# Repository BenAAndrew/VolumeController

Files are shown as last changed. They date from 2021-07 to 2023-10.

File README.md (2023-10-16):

# Volume Controller

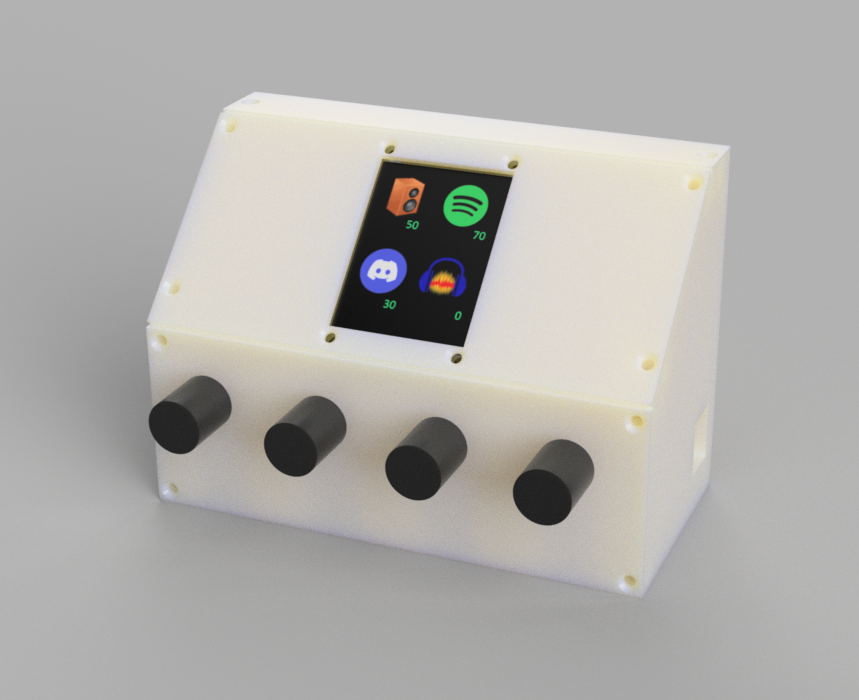
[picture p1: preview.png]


A physical multi-app volume controller. Control master volume and up to 3 other apps.

# Setup

## Parts
- Arduino Mega 2560
- ST7735 1.8" Color TFT Display
- 4x Rotary Encoders & Knobs
- Breadboard
- Wires

## [Wiring](firmware/WIRING.md)

## Installation

1. Upload the [Arduino sketch in the firmware folder](firmware/firmware.ino) to your Arduino
2. Run the desktop app. To do this you can either:
    - Download the executable in Releases and run
    - Install Python, dependencies and run `python main.py`

If this is done correctly the volume controller should now be working.

## [Assembly](assembly/ASSEMBLY.md)

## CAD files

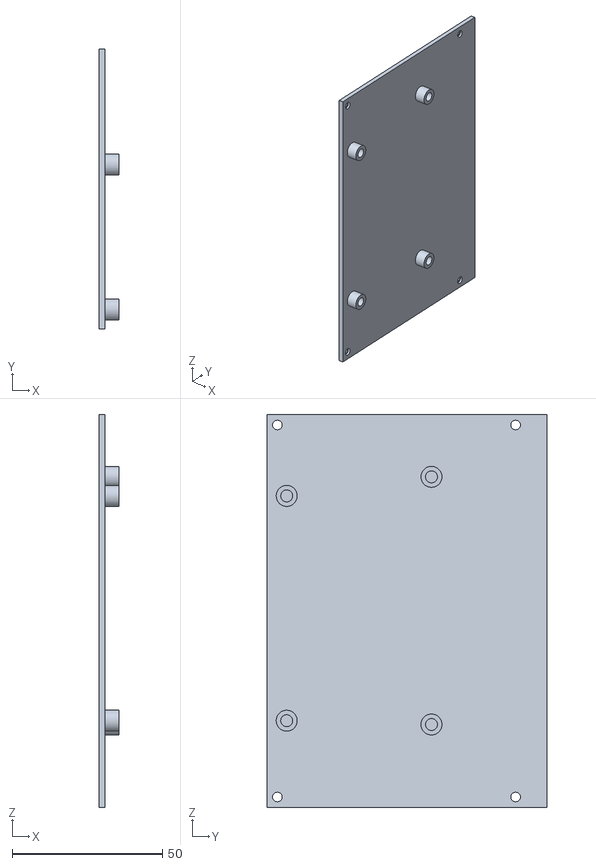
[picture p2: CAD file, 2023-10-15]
assembly/3d_models/Back.stl
6.80 x 93.4 x 131.0

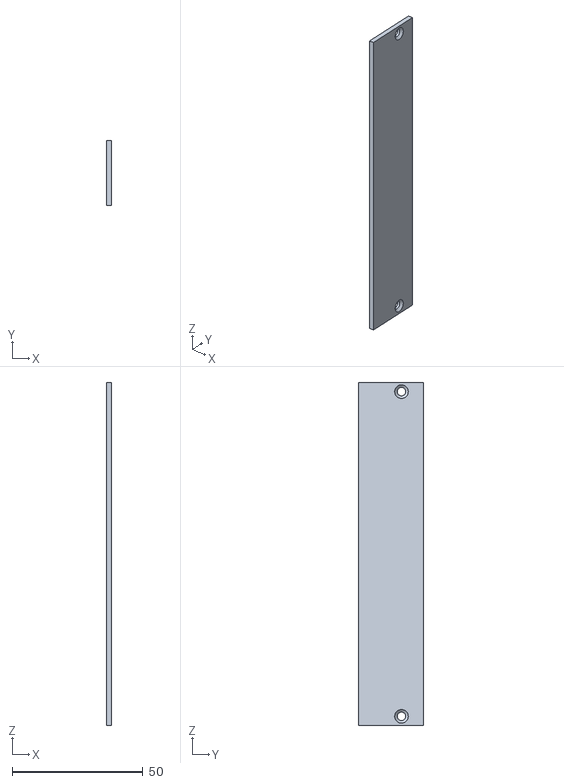
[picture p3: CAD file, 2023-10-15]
assembly/3d_models/Top.stl
2.00 x 25.0 x 131.0

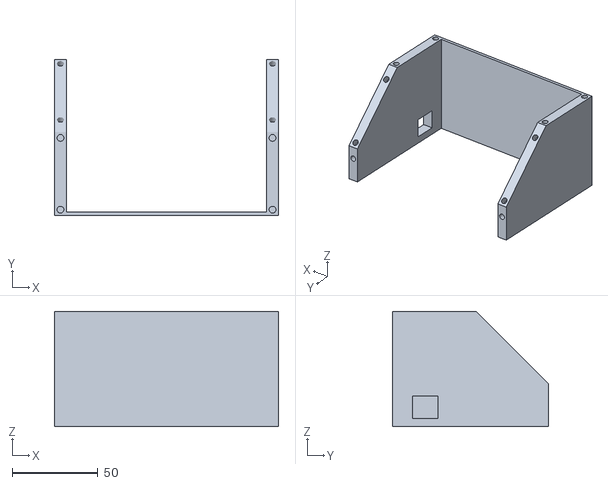
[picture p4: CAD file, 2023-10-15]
assembly/3d_models/Body.stl
131.0 x 91.4 x 67.4

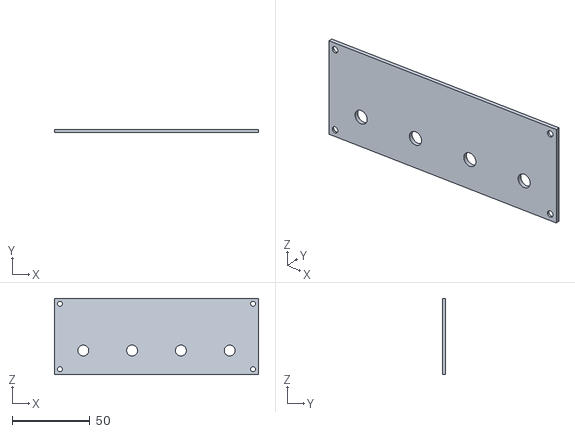
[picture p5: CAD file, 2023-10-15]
assembly/3d_models/Front.stl
131.0 x 2.00 x 49.0

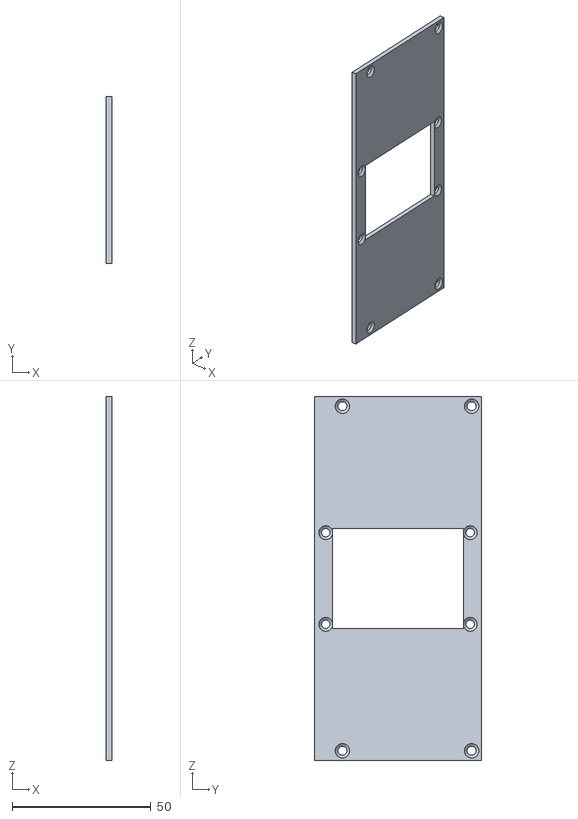
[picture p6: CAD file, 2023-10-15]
assembly/3d_models/Screen.stl
2.00 x 60.0 x 131.0

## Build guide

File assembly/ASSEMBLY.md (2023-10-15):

# Assembly

Before starting assembly, make sure you have the [electronics working and wires attached](../firmware/WIRING.md).

## Option A: 3D print
1. 3D print one of each STL file found in this folder
2. Insert [M3 heat inserts](https://uk.rs-online.com/web/p/threaded-inserts/0278534) into each hole on the body and the back piece
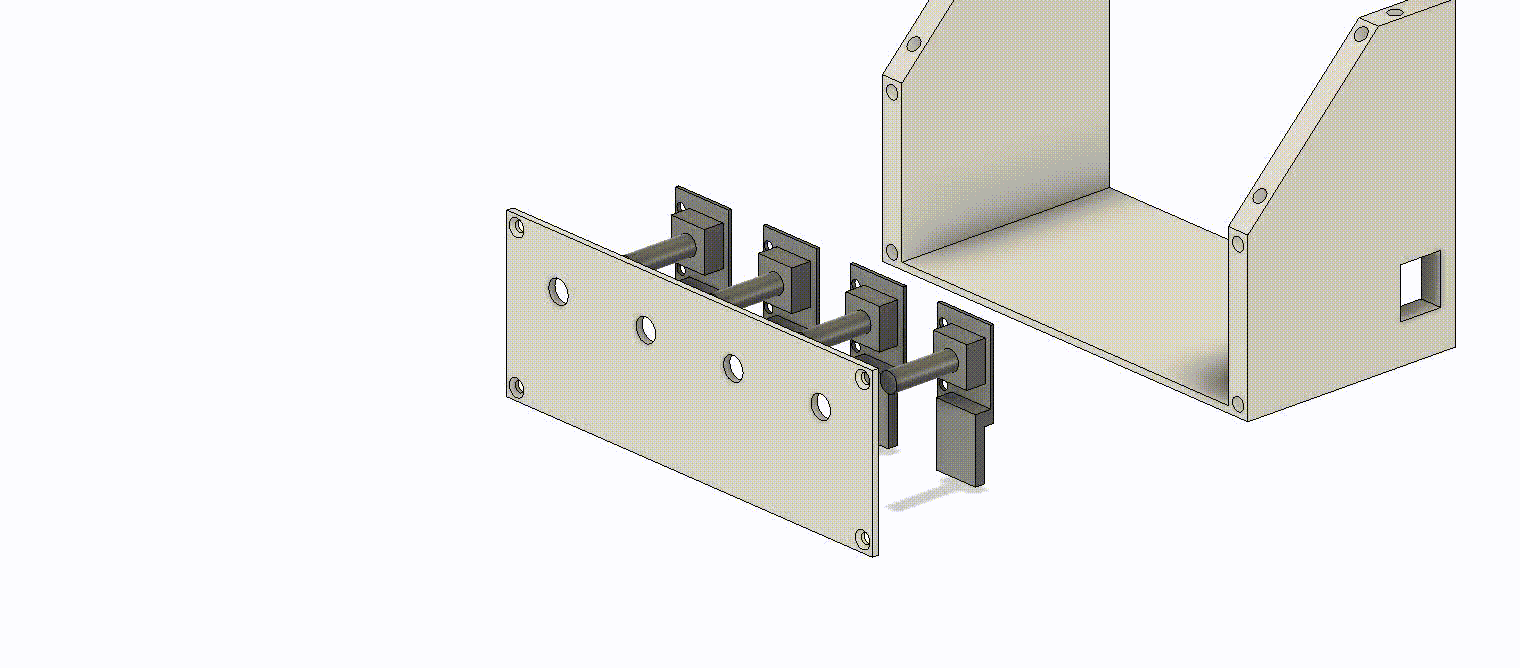
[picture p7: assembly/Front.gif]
3. Insert the encoders into the front piece, secure each with nuts, attach the knobs and then attach to the body 
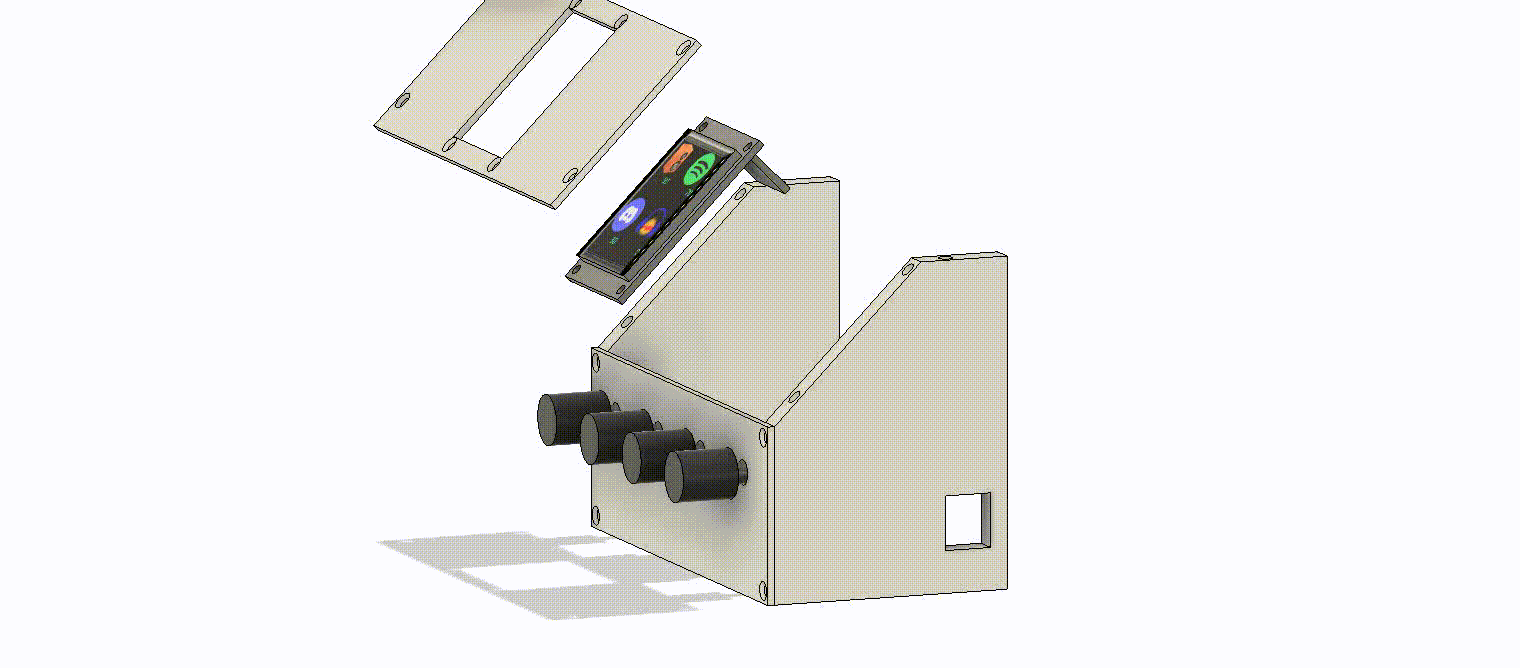
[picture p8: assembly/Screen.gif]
4. Insert the screen into the screen piece, then attach to the body 
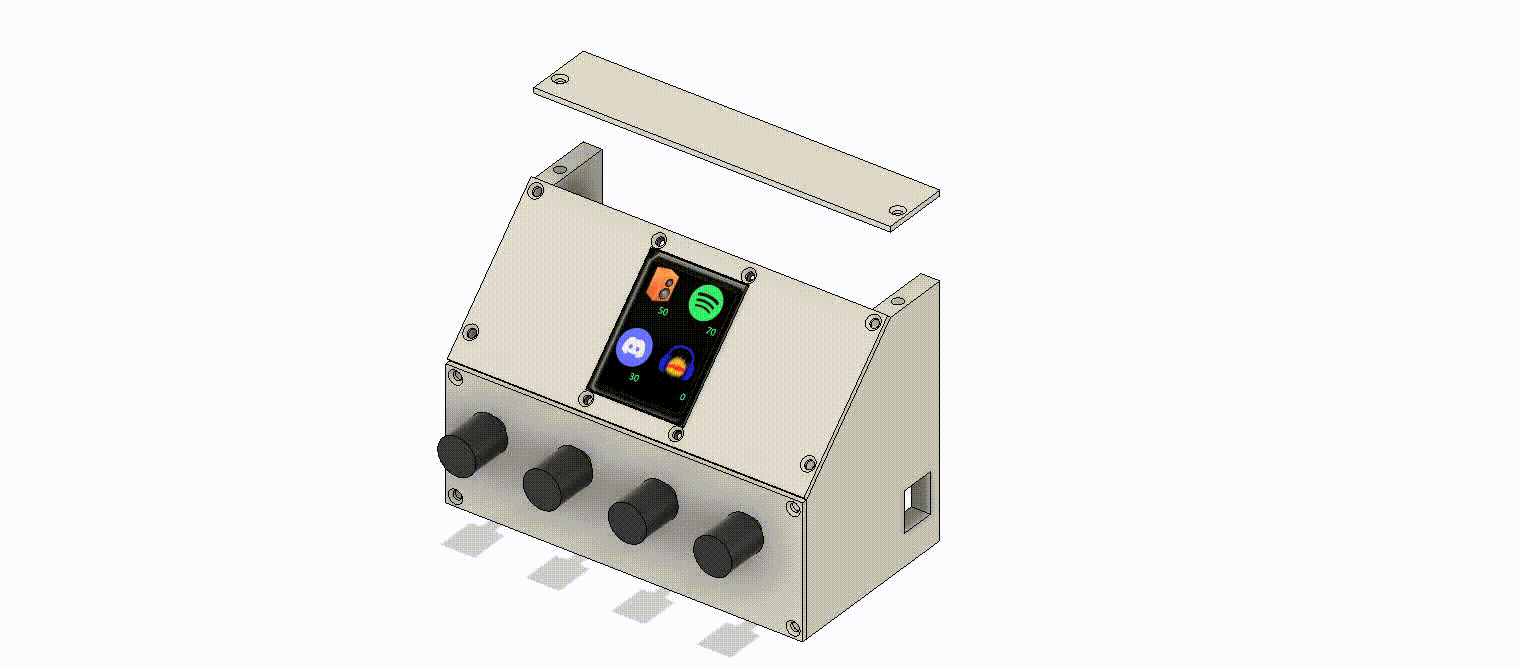
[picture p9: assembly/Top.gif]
5. Attach the top piece to the body 
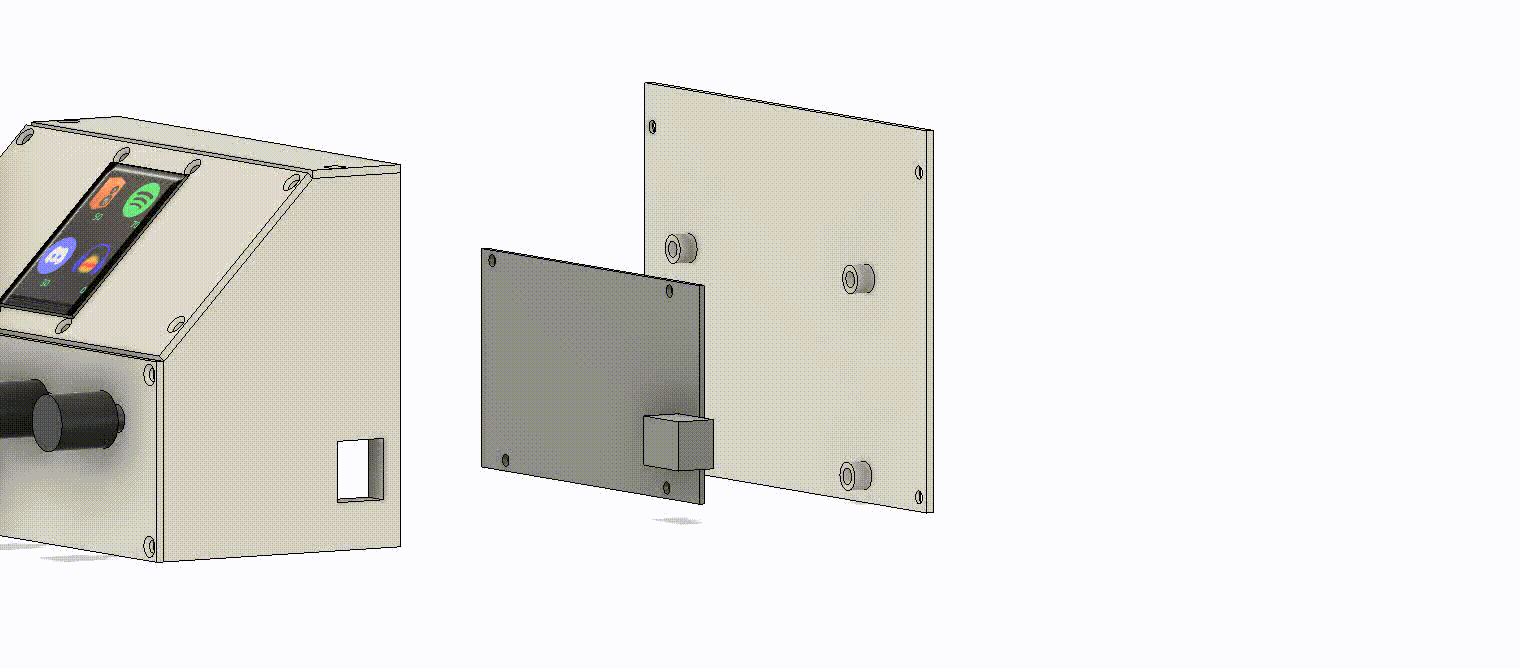
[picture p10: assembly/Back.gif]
6. Attach the arduino to the back piece, then attach to the body 

## Option B: 2D cut
Coming soon

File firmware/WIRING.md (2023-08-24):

# Wiring

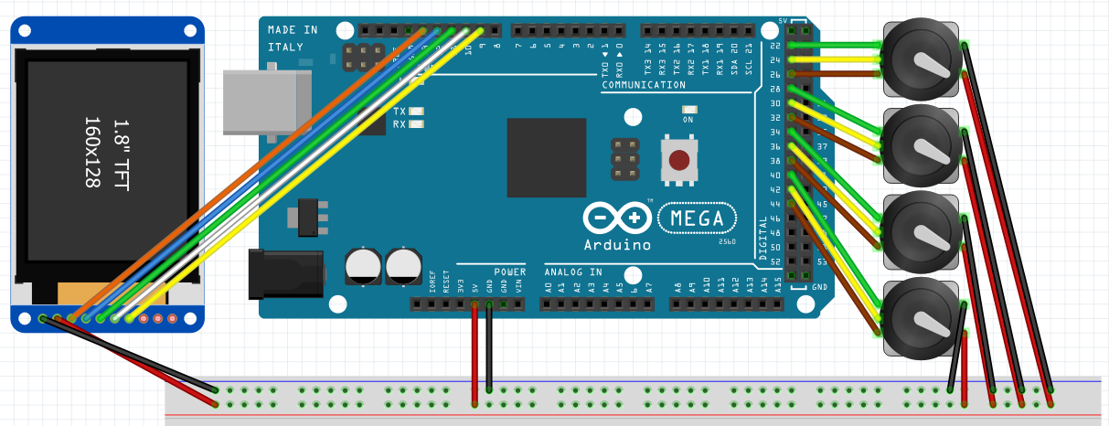
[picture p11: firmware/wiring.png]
wiring


## Display
- VCC = 5V
- GND = GND
- CLK/SCK = 13
- MOSI/SDA = 12
- CS = 11
- DC = 10
- RST = 9

8th Pin unconnected.

## Rotary encoders
- VCC/+ = 5V
- GND = GND

Master volume:
- SW = 22
- DT = 24
- CLK = 26

App 1:
- SW = 28
- DT = 30
- CLK = 32

App 2:
- SW = 34
- DT = 36
- CLK = 38

App 3:
- SW = 40
- DT = 42
- CLK = 44

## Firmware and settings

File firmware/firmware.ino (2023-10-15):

#include <Adafruit_GFX.h>    // Core graphics library
#include <Adafruit_ST7735.h> // Hardware-specific library
#include "Rotary_Encoder.h" // Hardware-specific library
#include <SPI.h>

// TFT Screen
#define sclk 13
#define mosi 12
#define cs   11
#define dc   10
#define rst  9

#define icon_size 60
#define icon_area icon_size*icon_size
#define margin_x 2
#define margin_y 10

Adafruit_ST7735 tft = Adafruit_ST7735(cs, dc, mosi, sclk, rst);
uint8_t r;
uint8_t g;
uint8_t b;

// Encoders
#define numEncoders 4
#define stepSize 2
#define pushDuration 10000

#define encoder1A 26
#define encoder1B 24
#define encoder1Btn 22

#define encoder2A 32
#define encoder2B 30
#define encoder2Btn 28

#define encoder3A 38
#define encoder3B 36
#define encoder3Btn 34

#define encoder4A 44
#define encoder4B 42
#define encoder4Btn 40

Rotary_Encoder encoders[] = {
  Rotary_Encoder(encoder1A, encoder1B, encoder1Btn, digitalRead(encoder1A)),
  Rotary_Encoder(encoder2A, encoder2B, encoder2Btn, digitalRead(encoder2A)),
  Rotary_Encoder(encoder3A, encoder3B, encoder3Btn, digitalRead(encoder3A)),
  Rotary_Encoder(encoder4A, encoder4B, encoder4Btn, digitalRead(encoder4A)),
};

// Variables
uint8_t command;
uint8_t output;
bool isConnected = false;

void setup() {
  // Screen setup
  tft.initR(INITR_BLACKTAB);
  tft.fillScreen(ST7735_BLACK);
  tft.setTextColor(ST7735_GREEN, ST7735_BLACK);
  tft.setTextSize(1);
  displayText(0, 150, "WAITING FOR APP...");

  // Encoder setup
  pinMode(encoder1A, INPUT);
  pinMode(encoder1B, INPUT);
  pinMode(encoder1Btn, INPUT_PULLUP);

  pinMode(encoder2A, INPUT);
  pinMode(encoder2B, INPUT);
  pinMode(encoder2Btn, INPUT_PULLUP);
  
  pinMode(encoder3A, INPUT);
  pinMode(encoder3B, INPUT);
  pinMode(encoder3Btn, INPUT_PULLUP);

  pinMode(encoder4A, INPUT);
  pinMode(encoder4B, INPUT);
  pinMode(encoder4Btn, INPUT_PULLUP);
  
  Serial.begin(14400);
}

void loop() {
  if (Serial.available() > 0) {
    command = getNextInput();
    if(command == 'i'){
      drawIcon();
    } else if(command == 'v'){
      displayVolume();
    } else if(command == 'm'){
      muteApp();
    } else if(command == 'd'){
      deleteApp();
    }
    if(!isConnected){
      isConnected = true;
      tft.fillRect(0, 150, 128, 160, ST7735_BLACK); 
    }
    Serial.write('d');
  }
  checkEncoders();
}

void checkEncoders(){
  for(uint8_t i = 0; i < numEncoders; i++){
    output = encoders[i].update(digitalRead(encoders[i].pinA), digitalRead(encoders[i].pinB), digitalRead(encoders[i].pinBtn));
    if(output != 0)
      Serial.write(output + (i * 10));
  }
}

uint8_t getXPosition(uint8_t index){
  uint8_t x = margin_x;
  if(index % 2 == 1){
    x += margin_x + icon_size;
  }
  return x;
}

uint8_t getYPosition(uint8_t index){
  uint8_t y = margin_y;
  if(index > 1){
    y += margin_y*2 + icon_size;
  }
  return y;
}

void displayText(uint8_t x, uint8_t y, String text){
  tft.setCursor(x,y);
  tft.print(text);
}

void displayVolume(){
  uint8_t pos = getNextInput();
  uint8_t volume = getNextInput();
  String text = String(volume) + ' ';
  if(volume < 9){
    text += ' ';
  }
  if(volume < 99){
    text += ' ';
  }
  uint8_t x = getXPosition(pos);
  uint8_t y = getYPosition(pos);
  displayText(x, y, text);
}

void drawIcon(){
  uint8_t pos = getNextInput();
  uint8_t x = getXPosition(pos);
  uint8_t y = getYPosition(pos);
  uint8_t starting_x = x;

  // Colours
  uint8_t num_colours = getNextInput();
  int colours[num_colours];
  for(uint8_t i = 0; i < num_colours; i++){
    r = getNextInput();
    g = getNextInput();
    b = getNextInput();
    colours[i] = tft.color565(r,g,b);
  }

  // Drawing
  uint8_t index;
  for(int pixel_counter = 0; pixel_counter < icon_area; pixel_counter++){
    index = getNextInput();
    tft.drawPixel(x, y, colours[index]);
    if(x == icon_size-1+starting_x){
      x = starting_x;
      y++;
    } else {
      x++;
    }
  }
}

void muteApp(){
  uint8_t pos = getNextInput();
  uint8_t x = getXPosition(pos);
  uint8_t y = getYPosition(pos);
  displayText(x, y, "MUTE");
}

void deleteApp(){
  uint8_t pos = getNextInput();
  uint8_t x = getXPosition(pos);
  uint8_t y = getYPosition(pos);
  tft.fillRect(x, y, x+icon_size, y+icon_size, ST7735_BLACK);
}

uint8_t getNextInput() {
  while(!Serial.available());
  return Serial.read();
}

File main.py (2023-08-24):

import threading
from comtypes import CoInitialize, CoUninitialize

from volume_controller.app import Application
from volume_controller.manager import Manager

thread = None
stop_thread = False


def close():
    global thread, stop_thread
    stop_thread = True
    thread.join()


def main(app):
    CoInitialize()
    manager = Manager(app)
    try:
        while not stop_thread:
            manager.update()
    except Exception as e:
        CoUninitialize()
        raise e


app = Application(on_close=close)
thread = threading.Thread(target=main, args=(app,))
thread.start()
app.run()

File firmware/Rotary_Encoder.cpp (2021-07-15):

#include "Rotary_Encoder.h"

Rotary_Encoder::Rotary_Encoder(unsigned int _pinA, unsigned int _pinB, unsigned int _pinBtn, unsigned int _a){
  index = 0;
  pinA = _pinA;
  pinB = _pinB;
  pinBtn = _pinBtn;
  pushDuration = 0;
  pushed = false;
  stepThreshold = 2;
  pushThreshold = 10000;
  previousVal = _a;
}

unsigned int Rotary_Encoder::update(unsigned int _a, unsigned int _b, unsigned int _button){
  // Push
  if (_button == 0 && !pushed){
    pushDuration++;
    if(pushDuration == pushThreshold){
      pushed = true;
      return index*10+3;
    }
  } else if(_button == 1){
    pushed = false;
    pushDuration = 0;
  }

  // Rotate
  if (_a != previousVal) {
    previousVal = _a;
    if (_b != _a) {
      totalRotation++;
      if(totalRotation == stepThreshold){
        totalRotation = 0;
        return index*10+2;
      }
    } else {
      totalRotation--;
      if(totalRotation == -stepThreshold){
        totalRotation = 0;
        return index*10+1;
      }
    }
  }
  
  return 0;
}

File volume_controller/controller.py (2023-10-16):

from dataclasses import dataclass
from enum import Enum
import serial
import time
import imageio

BAUDRATE = 14400
TIMEOUT = 0.1


class ControlEventType(Enum):
    VOLUME_UP = 0
    VOLUME_DOWN = 1
    TOGGLE_MUTE = 2


@dataclass
class ControlEvent:
    event_type: ControlEventType
    app_index: int


class AudioController:
    serial = None

    def connect(self):
        for i in range(2, 10):
            try:
                self.serial = serial.Serial(f"COM{i}", BAUDRATE, timeout=TIMEOUT)
                time.sleep(5)
                return True
            except:
                pass
        return False

    def initialize(self):
        connected = False
        while not connected:
            connected = self.connect()

    def wait_for_success(func):
        def wrapper(*args, **kwargs):
            func(*args, **kwargs)
            while not args[0].serial.read() == b"d":
                pass

        return wrapper

    # Arduino interactions
    @wait_for_success
    def send_icon(self, position, icon_path):
        self.serial.write(b"i")
        image = imageio.imread(icon_path)
        pixels = [tuple(p[:3]) for row in image for p in row]
        colours = list(set(pixels))
        self.serial.write(bytes([position, len(colours)]))

        for colour in colours:
            self.serial.write(bytes(colour))

        for pixel in pixels:
            self.serial.write(bytes([colours.index(pixel)]))

    @wait_for_success
    def send_volume(self, position, volume):
        self.serial.write(b"v")
        self.serial.write(bytes([position, volume]))

    @wait_for_success
    def mute_app(self, position):
        self.serial.write(b"m")
        self.serial.write(bytes([position]))

    @wait_for_success
    def delete_app(self, position):
        self.serial.write(b"d")
        self.serial.write(bytes([position]))

    def poll(self):
        data = int.from_bytes(self.serial.read(), "big")
        if data > 0:
            index = data // 10
            code = data % 10
            event_type = None

            # Anti-clockwise
            if code == 1:
                event_type = ControlEventType.VOLUME_DOWN
            # Clockwise
            elif code == 2:
                event_type = ControlEventType.VOLUME_UP
            # Press
            elif code == 3:
                event_type = ControlEventType.TOGGLE_MUTE

            if event_type is not None:
                return ControlEvent(event_type, index)

    def close(self):
        self.serial.close()

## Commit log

2021-06-30 Fix volume label setup
    [main.py]
2021-07-10 Add disable button
2021-07-10 Revert "Add disable action"
    This reverts commit 73a079b7d6594db78f6a9962247c79fcb8ffd93f.
    [controller.py, firmware.ino, main.py]
2021-07-10 Revert "Add disable button"
    This reverts commit dd33acea453ff739601d26b308a8c8199a38605c.
    [main.py]
2023-08-24 Fix display colour bleed
    [firmware.ino]
2023-08-24 Revert "Fix display colour bleed"
    This reverts commit 00c7171b67af29aac830201635c02177266dfcba.
    [firmware.ino]
2023-08-24 Add wiring instructions
    [VolumeController.fzz]
2023-08-25 Handle app enabled without available display slot
2023-08-25 Fill app slots if an app closes
2023-10-15 Add support for all encoders
2023-10-15 Fix app toggle mute
    [audio_interface.py]
2023-10-15 Add assembly guide
    [Back.stl, Body.stl, Front.stl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]
